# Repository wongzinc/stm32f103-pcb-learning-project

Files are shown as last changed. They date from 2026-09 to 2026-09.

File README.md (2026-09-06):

# STM32F103 PCB Learning Project

A custom 2-layer STM32F103C8T6 development board designed in **KiCad 10** as a project-driven introduction to PCB design, component selection, manufacturing preparation, and embedded hardware bring-up.

> **Status:** Rev. 1 PCB design complete. Manufacturing preparation and hardware bring-up in progress.

## Board Preview

| 3D view | Layout |
|---|---|
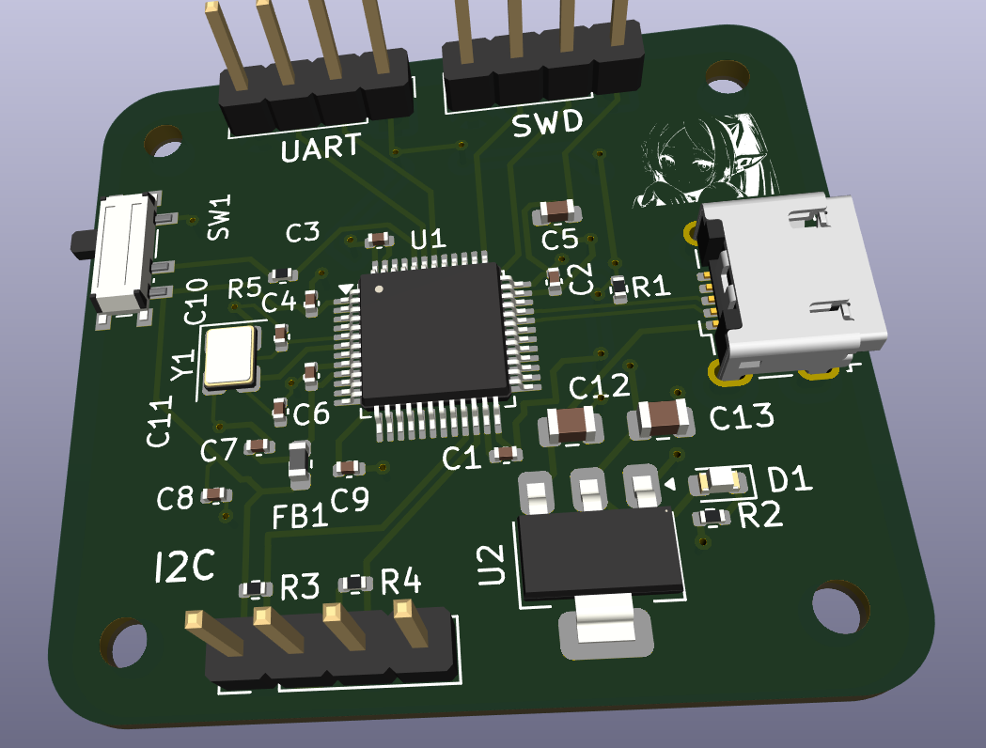
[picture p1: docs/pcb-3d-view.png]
PCB 3D view
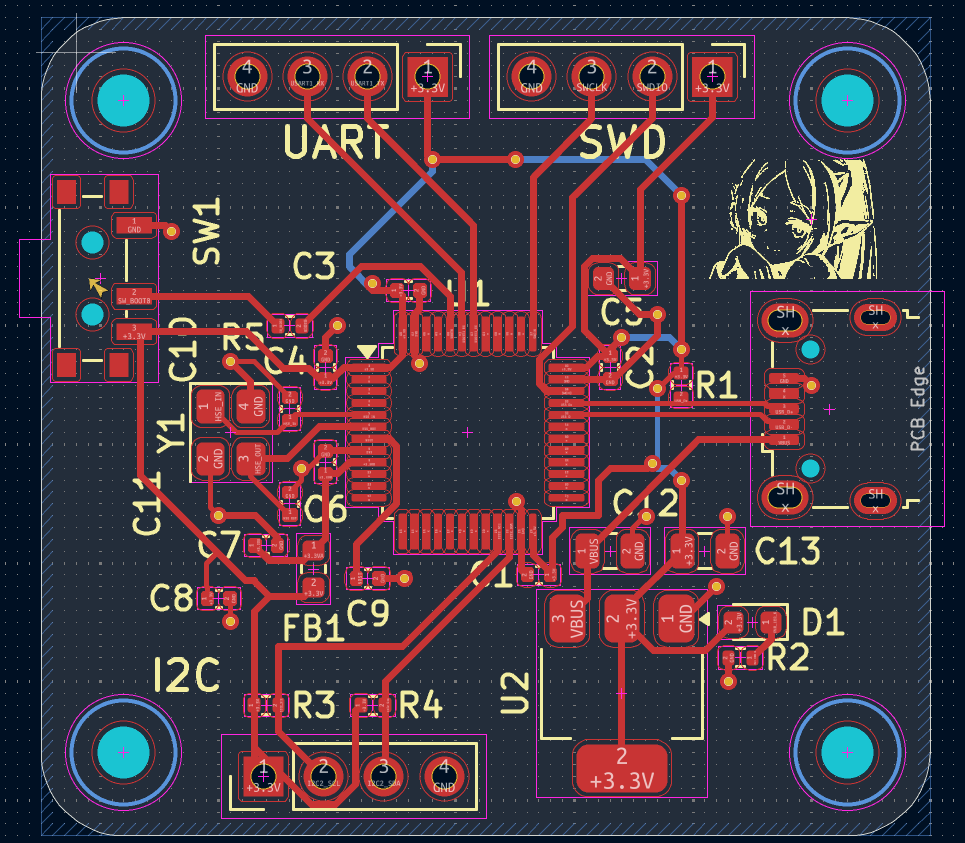
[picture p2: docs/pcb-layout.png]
PCB layout
|  |  |

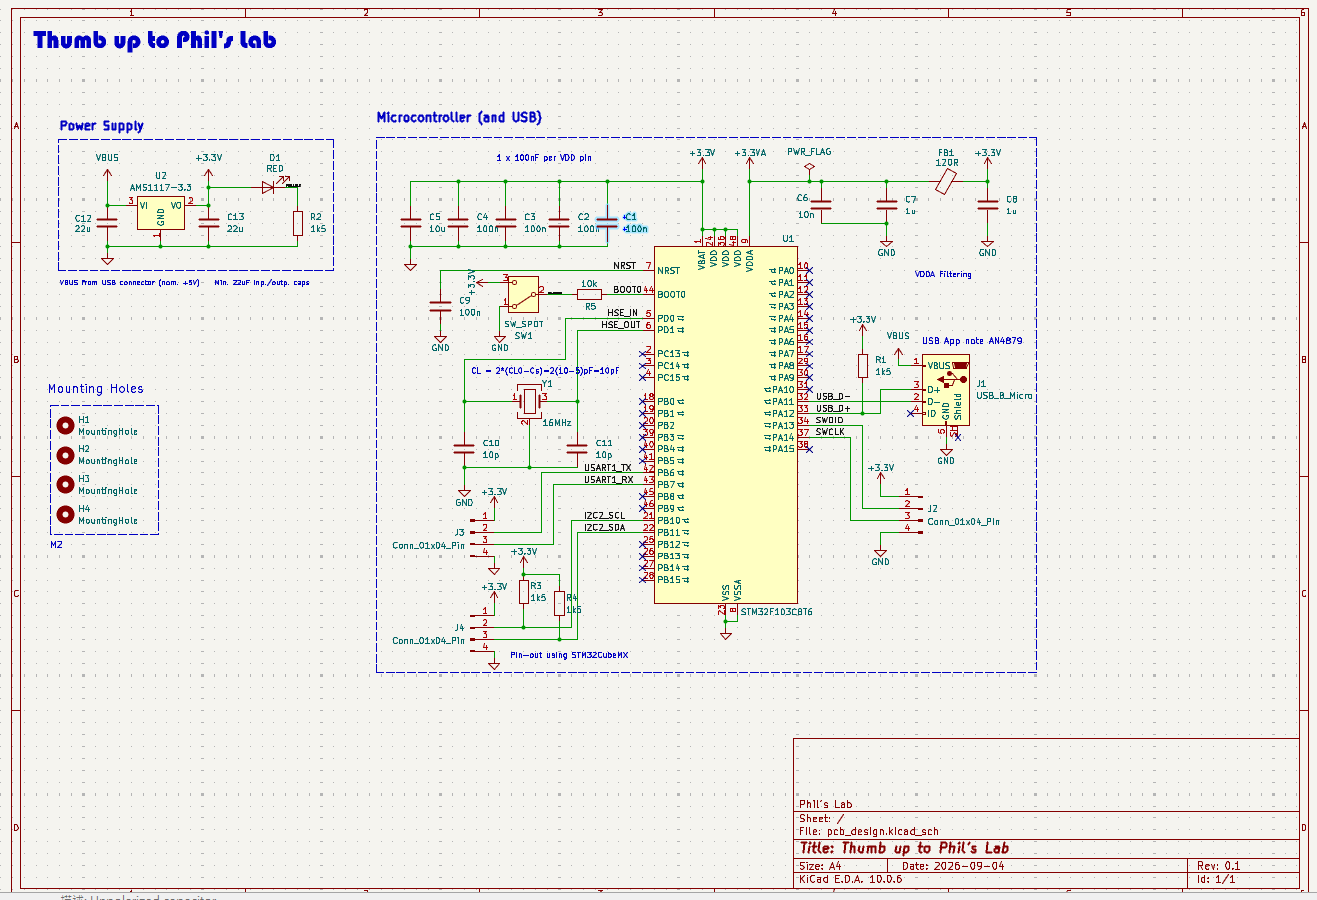
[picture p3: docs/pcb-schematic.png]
Schematic


## Project Goals

I started this project to learn PCB design by building a real microcontroller board rather than only studying individual concepts in isolation.

The goal was to walk the complete hardware workflow end to end:

```
datasheet → schematic → footprint selection → PCB layout
    → BOM / CPL → manufacturing preparation → hardware bring-up
```

## Board Features

| Block | Part |
|---|---|
| MCU | STM32F103C8T6 (LQFP-48) |
| Regulator | AMS1117-3.3 (SOT-223) |
| Clock | 16 MHz HSE crystal + load capacitors |
| Power input | Micro-USB B connector |
| Debug | SWD header |
| Serial | UART header |
| Bus | I²C header |
| Indicator | Status LED |
| Analog supply | Ferrite bead + filter capacitors on VDDA |
| Configuration | BOOT selection switch |
| Stackup | 2-layer, 1.6 mm |

## What I Learned

### 1. A schematic is more than connecting pins

Before this project, PCB design looked like drawing lines between components. Building an STM32 board forced me to work from the datasheet and application notes, and to understand *why* each connection exists.

Pins I had to actually understand rather than just wire up:

- `VDD` / `VSS` — digital power and return
- `VDDA` / `VSSA` — analog power, filtered separately
- `NRST` — reset, with its own RC
- `BOOT0` — boot mode selection at reset
- `OSC_IN` / `OSC_OUT` — HSE crystal
- `SWDIO` / `SWCLK` — debug interface
- UART, I²C, and the USB connector signals

### 2. Power distribution is a system, not a net

The board generates 3.3 V from an AMS1117-3.3. Learning to design around it meant separating concepts I had previously treated as one thing:

- voltage regulation
- bulk capacitance
- local decoupling
- analog supply filtering
- power rails
- ground planes and return paths

The lesson that stuck: a decoupling capacitor is not just "electrically connected" to a power pin. Its **physical placement and current loop are part of the circuit**.

### 3. Capacitors map to frequency, not to a generic "filtering" role

This was the concept that changed how I read schematics. The board uses six different capacitor values, and they are not interchangeable — each one covers a different part of the frequency spectrum.

| Value | Package | Qty | Role |
|---|---|---|---|
| 22 µF | 0805 | 2 | Bulk — regulator input and output reservoir |
| 10 µF | 0603 | 1 | Bulk / rail stabilisation |
| 1 µF | 0402 | 2 | Mid-band, bridges bulk and local decoupling |
| 100 nF | 0402 | 5 | Local decoupling, one per MCU supply pin |
| 10 nF | 0402 | 1 | Analog supply filtering with the ferrite bead |
| 10 pF | 0402 | 2 | Crystal load capacitors — not decoupling at all |

#### Why one value cannot do the whole job

A real capacitor is not just capacitance. It behaves as C in series with **ESR** (resistance) and **ESL** (parasitic inductance from the leads, pads, and internal structure). That series combination has a **self-resonant frequency**:

```
f_SRF = 1 / (2π √(L·C))
```

Below the SRF the part behaves like a capacitor and its impedance falls with frequency. Above the SRF the inductance dominates and impedance *rises* again — the capacitor stops being a capacitor.

Two consequences follow:

- **Larger capacitance → lower SRF.** A 22 µF part is effective in the kHz to low-MHz range and is essentially useless above it.
- **Larger package → higher ESL → lower SRF and a higher impedance floor.** This is why the 100 nF parts are 0402 and not 0805; the package matters as much as the value.

So the values are chosen to overlap. The 22 µF absorbs slow load steps and regulator ripple. The 100 nF supplies the fast current spikes the MCU draws every time its internal logic switches, at tens of MHz, where the bulk capacitor is already inductive.

#### Low-frequency ripple vs high-frequency transients

These are two genuinely different problems:

**Low-frequency ripple** comes from the regulator itself and from slow changes in load current. The AMS1117 is a linear regulator, so there is no switching ripple to filter, but its control loop has finite bandwidth — it cannot respond instantly to a load step. Bulk capacitance covers the gap by acting as a local charge reservoir until the regulator catches up. Here the value is what matters; a few millimetres of trace inductance is negligible at these frequencies.

**High-frequency transients** come from inside the MCU. Every clock edge switches millions of gates, and each switching event draws a short, sharp current pulse. That current has to come from somewhere, and it cannot travel far — at 100 MHz, a few millimetres of trace can contribute more inductance than the capacitor itself. This is why local decoupling is a *layout* problem: the 100 nF has to sit within a few millimetres of its VDD pin, with a short via straight down to the ground plane, so the current loop stays small.

The rule I took away: **large value, near the regulator; small value, near the pin.**

#### One caveat I ran into while reading

The classic advice to parallel a decade spread of values (10 µF ‖ 1 µF ‖ 100 nF) has a known downside — **anti-resonance**. Between two capacitors' SRFs, one is already inductive while the other is still capacitive, and the resulting parallel LC can produce an impedance *peak*. Modern practice often favours several capacitors of the same value over a wide spread. For a learning board at these speeds it does not matter much, but it is worth knowing that the textbook rule is a simplification.

#### Analog supply filtering

`VDDA` gets a ferrite bead (FB1, 120 Ω) plus its own capacitors. The bead is not an inductor in the ideal sense — at high frequency it becomes largely **resistive**, so it dissipates noise energy as heat rather than reflecting it back into the rail. Together with the capacitors it forms a low-pass filter that keeps digital switching noise out of the ADC reference.

#### Crystal load capacitors are a different animal

C10 and C11 (10 pF) are not decoupling. They set the oscillator's load capacitance, which has to match what the crystal specifies:

```
C_L = (C1 × C2) / (C1 + C2) + C_stray
```

Getting these wrong does not cause noise — it shifts the oscillator frequency, or stops it starting at all. `C_stray` includes the PCB traces and the MCU pin capacitance, which is why these traces are kept short.

### 4. Crystal selection is more than a frequency number

Choosing the 16 MHz HSE crystal meant checking:

- package size
- load capacitance (which sets C10/C11 above)
- ESR, against the MCU's oscillator drive capability
- frequency tolerance and temperature drift
- placement — short traces to `OSC_IN` / `OSC_OUT`, guarded from other signals

### 5. SWD, UART and I²C serve different purposes

- **SWD** — programming and debugging, two wires plus reset
- **UART** — asynchronous point-to-point serial
- **I²C** — shared two-wire bus

I²C in particular taught me why `SDA` and `SCL` need pull-up resistors: the bus is **open-drain**, so devices can only pull low. The pull-ups provide the high level, and their value trades rise time against current draw.

### 6. Symbol vs footprint vs physical component

These are three different things, and confusing them is expensive.

- A **schematic symbol** describes the *electrical function* — how many pins and what they do.
- A **footprint** describes the *physical pads and dimensions* on the board.
- The **physical component** is what actually ships.

The naming taught me this the hard way:

```
KiCad footprint:  C_0402_1005Metric

0402  = imperial package code (0.04" × 0.02")
1005  = metric package code  (1.0 mm × 0.5 mm)

Same part. Two measuring systems. One physical size.
```

The trap: metric `0402` is a real and completely different package — 0.4 × 0.2 mm, known as imperial `01005`. A component can have the correct electrical value and still be entirely wrong if the package does not match the footprint on the board.

### 7. Automatic BOM matching cannot be trusted

While preparing the board for assembly, several automatically matched components came back with the wrong package. In one case every 0402 capacitor and resistor had been matched to `01005` parts — six times smaller in area, out of stock, and flagged as high assembly difficulty.

I now verify every line against:

- value
- package / footprint
- voltage or power rating
- tolerance
- dielectric (C0G vs X5R vs X7R) where it matters
- stock availability and whether the part is basic or extended

The connectors, switch, and crystal needed the most attention — for those, matching on a description string is not reliable, and specifying a manufacturer part number is the only dependable approach.

### 8. Layout is an electrical problem

Routing is not about making the ratsnest disappear. During layout I practised:

- component placement driven by signal flow
- trace routing and width
- via placement and count
- ground-plane continuity
- decoupling capacitors close to their pins
- minimising oscillator trace length
- connectors at the board edge
- readable silkscreen
- mechanical mounting holes

I also started thinking about **return-current paths** — the current in the ground plane underneath a trace, rather than just the forward signal.

## Manufacturing Workflow

```
KiCad schematic
      ↓
PCB layout + footprints
      ↓
Gerber / drill files
      ↓
BOM (with manufacturer part numbers)
      ↓
CPL / position file
      ↓
Manufacturer part matching + verification
      ↓
PCB fabrication / assembly
```

## Bring-up Plan

When the board arrives, I plan to validate it in this order — stopping at the first failure rather than powering everything at once:

- [ ] Visual inspection for bridges and misaligned parts
- [ ] Continuity check: 3.3 V to GND, confirm no short
- [ ] Apply input voltage, measure USB / `VBUS`
- [ ] Verify the regulated 3.3 V rail under no load
- [ ] Check rail ripple on a scope
- [ ] Connect ST-Link over SWD
- [ ] Read the MCU device ID
- [ ] Flash a minimal LED blink program
- [ ] Verify HSE oscillator start-up and frequency
- [ ] Test UART loopback
- [ ] Test I²C with a known device
- [ ] Exercise the remaining interfaces

## Planned Rev. 2 Improvements

Rev. 1 is a learning prototype, not a finished design. After bring-up I plan to review:

- component placement and grouping
- routing cleanliness and return paths
- oscillator layout
- USB signal routing and impedance
- footprint selection against real, in-stock parts
- BOM cost and availability
- DFM / DFA considerations
- test-point accessibility
- whether to move from Micro-USB to USB-C

## Repository Layout

```
.
├── pcb_design.kicad_pro
├── pcb_design.kicad_sch
├── pcb_design.kicad_pcb
├── 629105150521_rev1.stp     # 3D model, Micro-USB connector
├── docs/                     # images used in this README
├── manufacturing/            # Gerber, drill, BOM, CPL
└── README.md
```

## Tools

- KiCad 10
- STM32CubeMX
- STM32CubeIDE
- Git / GitHub
- JLCPCB / LCSC

## Project Status

**Revision 1** — PCB design complete, manufacturing preparation in progress.

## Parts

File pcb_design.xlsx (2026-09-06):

Designator | Qty | Comment | DNP | Exclude from BOM | Exclude from Board | Exclude from Simulation | Exclude from Position Files | Footprint | Datasheet
C1,C2,C3,C4,C9 | 5 | 100n |  |  |  |  | ${EXCLUDE_FROM_POS_FILES} | Capacitor_SMD:C_0402_1005Metric
C5 | 1 | 10u |  |  |  |  | ${EXCLUDE_FROM_POS_FILES} | Capacitor_SMD:C_0603_1608Metric
C6 | 1 | 10n |  |  |  |  | ${EXCLUDE_FROM_POS_FILES} | Capacitor_SMD:C_0402_1005Metric
C7,C8 | 2 | 1u |  |  |  |  | ${EXCLUDE_FROM_POS_FILES} | Capacitor_SMD:C_0402_1005Metric
C10,C11 | 2 | 10p |  |  |  |  | ${EXCLUDE_FROM_POS_FILES} | Capacitor_SMD:C_0402_1005Metric
C12,C13 | 2 | 22u |  |  |  |  | ${EXCLUDE_FROM_POS_FILES} | Capacitor_SMD:C_0805_2012Metric
D1 | 1 | RED |  |  |  |  | ${EXCLUDE_FROM_POS_FILES} | LED_SMD:LED_0603_1608Metric
FB1 | 1 | 120R |  |  |  |  | ${EXCLUDE_FROM_POS_FILES} | Inductor_SMD:L_0603_1608Metric
J1 | 1 | USB_B_Micro |  |  |  |  | ${EXCLUDE_FROM_POS_FILES} | Connector_USB:USB_Micro-B_Wuerth_629105150521
J2,J3,J4 | 3 | Conn_01x04_Pin |  |  |  |  | ${EXCLUDE_FROM_POS_FILES} | Connector_PinHeader_2.54mm:PinHeader_1x04_P2.54mm_Vertical
R1,R2,R3,R4 | 4 | 1k5 |  |  |  |  | ${EXCLUDE_FROM_POS_FILES} | Resistor_SMD:R_0402_1005Metric
R5 | 1 | 10k |  |  |  |  | ${EXCLUDE_FROM_POS_FILES} | Resistor_SMD:R_0402_1005Metric
SW1 | 1 | SW_SPDT |  |  |  |  | ${EXCLUDE_FROM_POS_FILES} | Button_Switch_SMD:SW_SPDT_PCM12
U1 | 1 | STM32F103C8T6 |  |  |  |  | ${EXCLUDE_FROM_POS_FILES} | Package_QFP:LQFP-48_7x7mm_P0.5mm | https://www.st.com/resource/en/datasheet/stm32f103c8.pdf
U2 | 1 | AMS1117-3.3 |  |  |  |  | ${EXCLUDE_FROM_POS_FILES} | Package_TO_SOT_SMD:SOT-223-3_TabPin2 | http://www.advanced-monolithic.com/pdf/ds1117.pdf
Y1 | 1 | 16MHz |  |  |  |  | ${EXCLUDE_FROM_POS_FILES} | Crystal:Crystal_SMD_3225-4Pin_3.2x2.5mm
Designator | Qty | Comment | Footprint
C1,C2,C3,C4,C9 | 5 | 100n | 0402
C5 | 1 | 10u | 0603
C6 | 1 | 10n | 0402
C7,C8 | 2 | 1u | 0402
C10,C11 | 2 | 10p | 0402
C12,C13 | 2 | 22u | 0805
D1 | 1 | RED | 0603
FB1 | 1 | 120R | 0603
J1 | 1 | USB_B_Micro
J2,J3,J4 | 3 | Conn_01x04_Pin
R1,R2,R3,R4 | 4 | 1k5
R5 | 1 | 10k
SW1 | 1 | SW_SPDT
U1 | 1 | STM32F103C8T6
U2 | 1 | AMS1117-3.3
Y1 | 1 | 16MHz

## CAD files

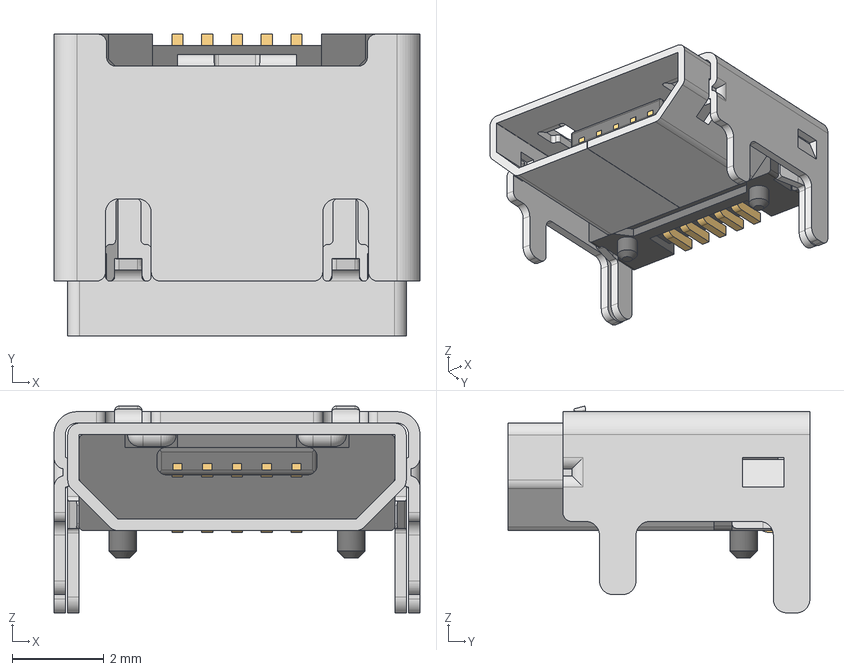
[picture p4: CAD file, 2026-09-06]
629105150521 (rev1).stp
8.00 x 6.60 x 4.52 mm
629105150521_Housing
629105150521_Pin1 x 4
629105150521_Pin2
629105150521_Shielding2
629105150521_Shielding

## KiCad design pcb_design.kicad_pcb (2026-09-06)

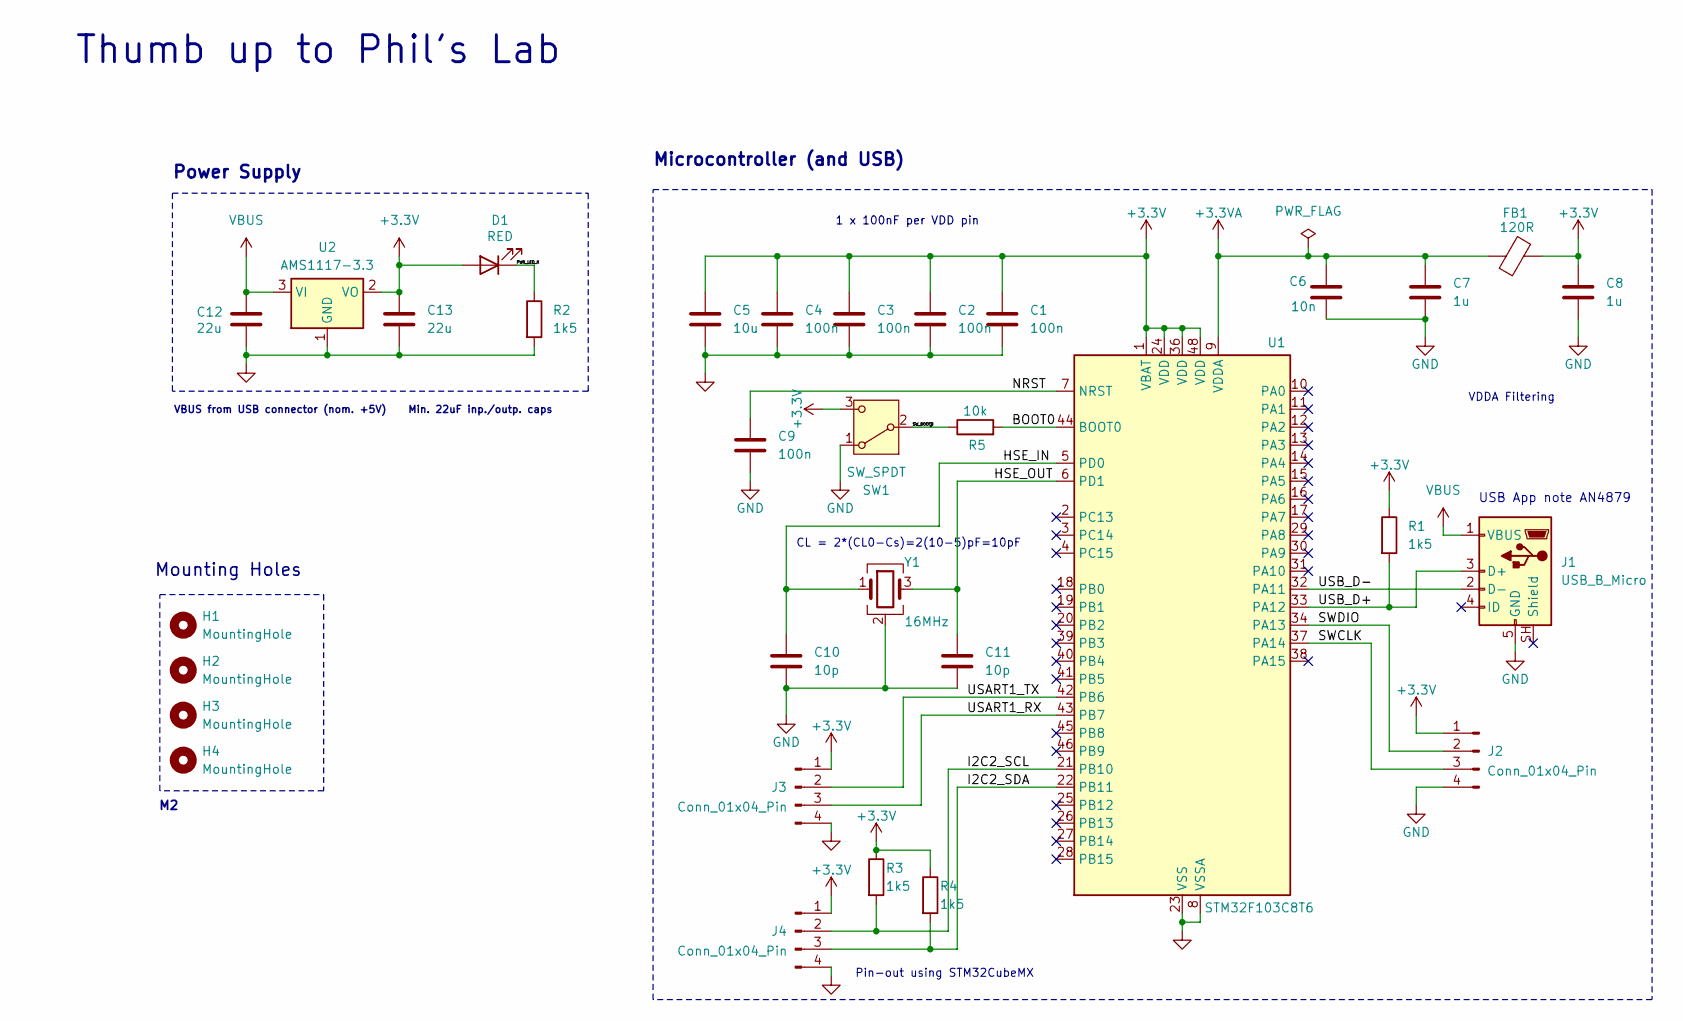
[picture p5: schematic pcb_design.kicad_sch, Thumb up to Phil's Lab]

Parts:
C1, C2, C3, C4, C9: 100n; C_0402_1005Metric
C5: 10u; C_0603_1608Metric
C6: 10n; C_0402_1005Metric
C7, C8: 1u; C_0402_1005Metric
C10, C11: 10p; C_0402_1005Metric
C12, C13: 22u; C_0805_2012Metric
D1: RED; LED_0603_1608Metric
FB1: 120R; L_0603_1608Metric
H1, H2, H3, H4: MountingHole; MountingHole_2.2mm_M2
J1: USB_B_Micro; USB_Micro-B_Wuerth_629105150521
J2, J3, J4: Conn_01x04_Pin; PinHeader_1x04_P2.54mm_Vertical
R1, R2, R3, R4: 1k5; R_0402_1005Metric
R5: 10k; R_0402_1005Metric
SW1: SW_SPDT; SW_SPDT_PCM12
U1: STM32F103C8T6; LQFP-48_7x7mm_P0.5mm
U2: AMS1117-3.3; SOT-223-3_TabPin2
Y1: 16MHz; Crystal_SMD_3225-4Pin_3.2x2.5mm

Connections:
+3.3V: C1.1, C2.1, C3.1, C4.1, C5.1, C8.1, C13.1, D1.2 (A), FB1.2, J2.1, J3.1, J4.1, R1.1, R3.1, R4.1, SW1.3 (C), U1.1 (VBAT), U1.24 (VDD), U1.36 (VDD), U1.48 (VDD), U2.2 (VO)
+3.3VA: C6.1, C7.1, FB1.1, U1.9 (VDDA)
/BOOT0: R5.2, U1.44 (BOOT0)
/HSE_IN: C10.1, U1.5 (PD0), Y1.1
/HSE_OUT: C11.1, U1.6 (PD1), Y1.3
/I2C2_SCL: J4.2, R3.2, U1.21 (PB10)
/I2C2_SDA: J4.3, R4.2, U1.22 (PB11)
/NRST: C9.1, U1.7 (NRST)
/PWR_LED_K: D1.1 (K), R2.1
/SWCLK: J2.3, U1.37 (PA14)
/SWDIO: J2.2, U1.34 (PA13)
/SW_BOOT0: R5.1, SW1.2 (B)
/USART1_RX: J3.3, U1.43 (PB7)
/USART1_TX: J3.2, U1.42 (PB6)
/USB_D+: J1.3 (D+), R1.2, U1.33 (PA12)
/USB_D-: J1.2 (D-), U1.32 (PA11)
GND: C1.2, C2.2, C3.2, C4.2, C5.2, C6.2, C7.2, C8.2, C9.2, C10.2, C11.2, C12.2, C13.2, J1.5 (GND), J2.4, J3.4, J4.4, R2.2, SW1.1 (A), U1.8 (VSSA), U1.23 (VSS), U1.35 (VSS), U1.47 (VSS), U2.1 (GND), Y1.2 (G), Y1.4 (G)
VBUS: C12.1, J1.1 (VBUS), U2.3 (VI)

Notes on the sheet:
VBUS from USB connector (nom. +5V) Min. 22uF inp./outp. caps
Microcontroller (and USB)
USB App note AN4879
Mounting Holes
CL = 2*(CL0-Cs)=2(10-5)pF=10pF
Pin-out using STM32CubeMX
Thumb up to Phil's Lab
1 x 100nF per VDD pin
Power Supply
VDDA Filtering

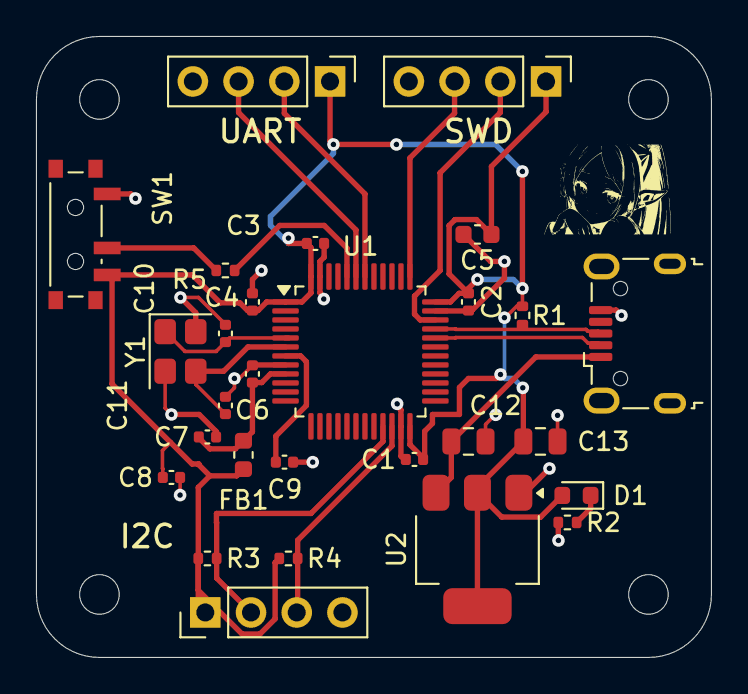
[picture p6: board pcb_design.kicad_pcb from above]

Board: 2 copper layers, 37.5 x 34.5 mm, 32 parts (0 on the bottom side), 18 nets.

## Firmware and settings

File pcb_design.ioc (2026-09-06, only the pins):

Mcu.UserName=STM32F103C8Tx
PA11.Signal=USB_DM
PA12.Signal=USB_DP
PA13.Signal=SYS_JTMS-SWDIO
PA14.Signal=SYS_JTCK-SWCLK
PB10.Signal=I2C2_SCL
PB11.Signal=I2C2_SDA
PB6.Signal=USART1_TX
PB7.Signal=USART1_RX
PD0-OSC_IN.Signal=RCC_OSC_IN
PD1-OSC_OUT.Signal=RCC_OSC_OUT

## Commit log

2026-09-06 Initial STM32F103 PCB design
    [629105150521 (rev1).stp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]
2026-09-06 Add detailed README for STM32F103 PCB project
    Added comprehensive documentation for the STM32F103 PCB learning project, including project goals, features, lessons learned, manufacturing workflow, and planned improvements.
2026-09-06 Fix schematic image link in README.md
    Updated schematic image link in README.
